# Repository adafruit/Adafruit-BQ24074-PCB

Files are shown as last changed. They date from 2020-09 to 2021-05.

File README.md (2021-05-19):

## Adafruit BQ24074 Solar Charger PCB

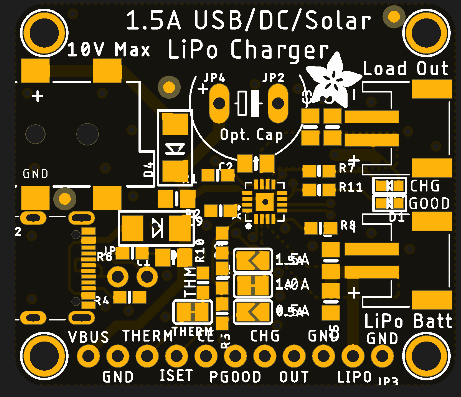
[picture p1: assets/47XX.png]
<a href="https://www.adafruit.com/product/4755"><br/>
Click here to purchase one from the Adafruit shop</a>

PCB files for the Adafruit BQ24074 Solar Charger. 

Format is EagleCAD schematic and board layout
* https://www.adafruit.com/product/4755

### Description

This charger is the only one you need to keep all your Lithium Polymer (LiPoly) or Lithium Ion (LiIon) rechargeable batteries topped up. No matter the power source at your disposal! The Adafruit Universal USB / DC / Solar Lithium Ion/Polymer Charger can use USB, DC or Solar power, with a wide 5-10V input voltage range! The charger chip is super smart, and will reduce the current draw if the input voltage starts to dip under 4.5V, making it a perfect near-MPPT solar charger that you can use with a wide range of panels.

### License

Adafruit invests time and resources providing this open source design, please support Adafruit and open-source hardware by purchasing products from [Adafruit](https://www.adafruit.com)!

Designed by Limor Fried/Ladyada for Adafruit Industries.

Creative Commons Attribution/Share-Alike, all text above must be included in any redistribution. 
See license.txt for additional details.

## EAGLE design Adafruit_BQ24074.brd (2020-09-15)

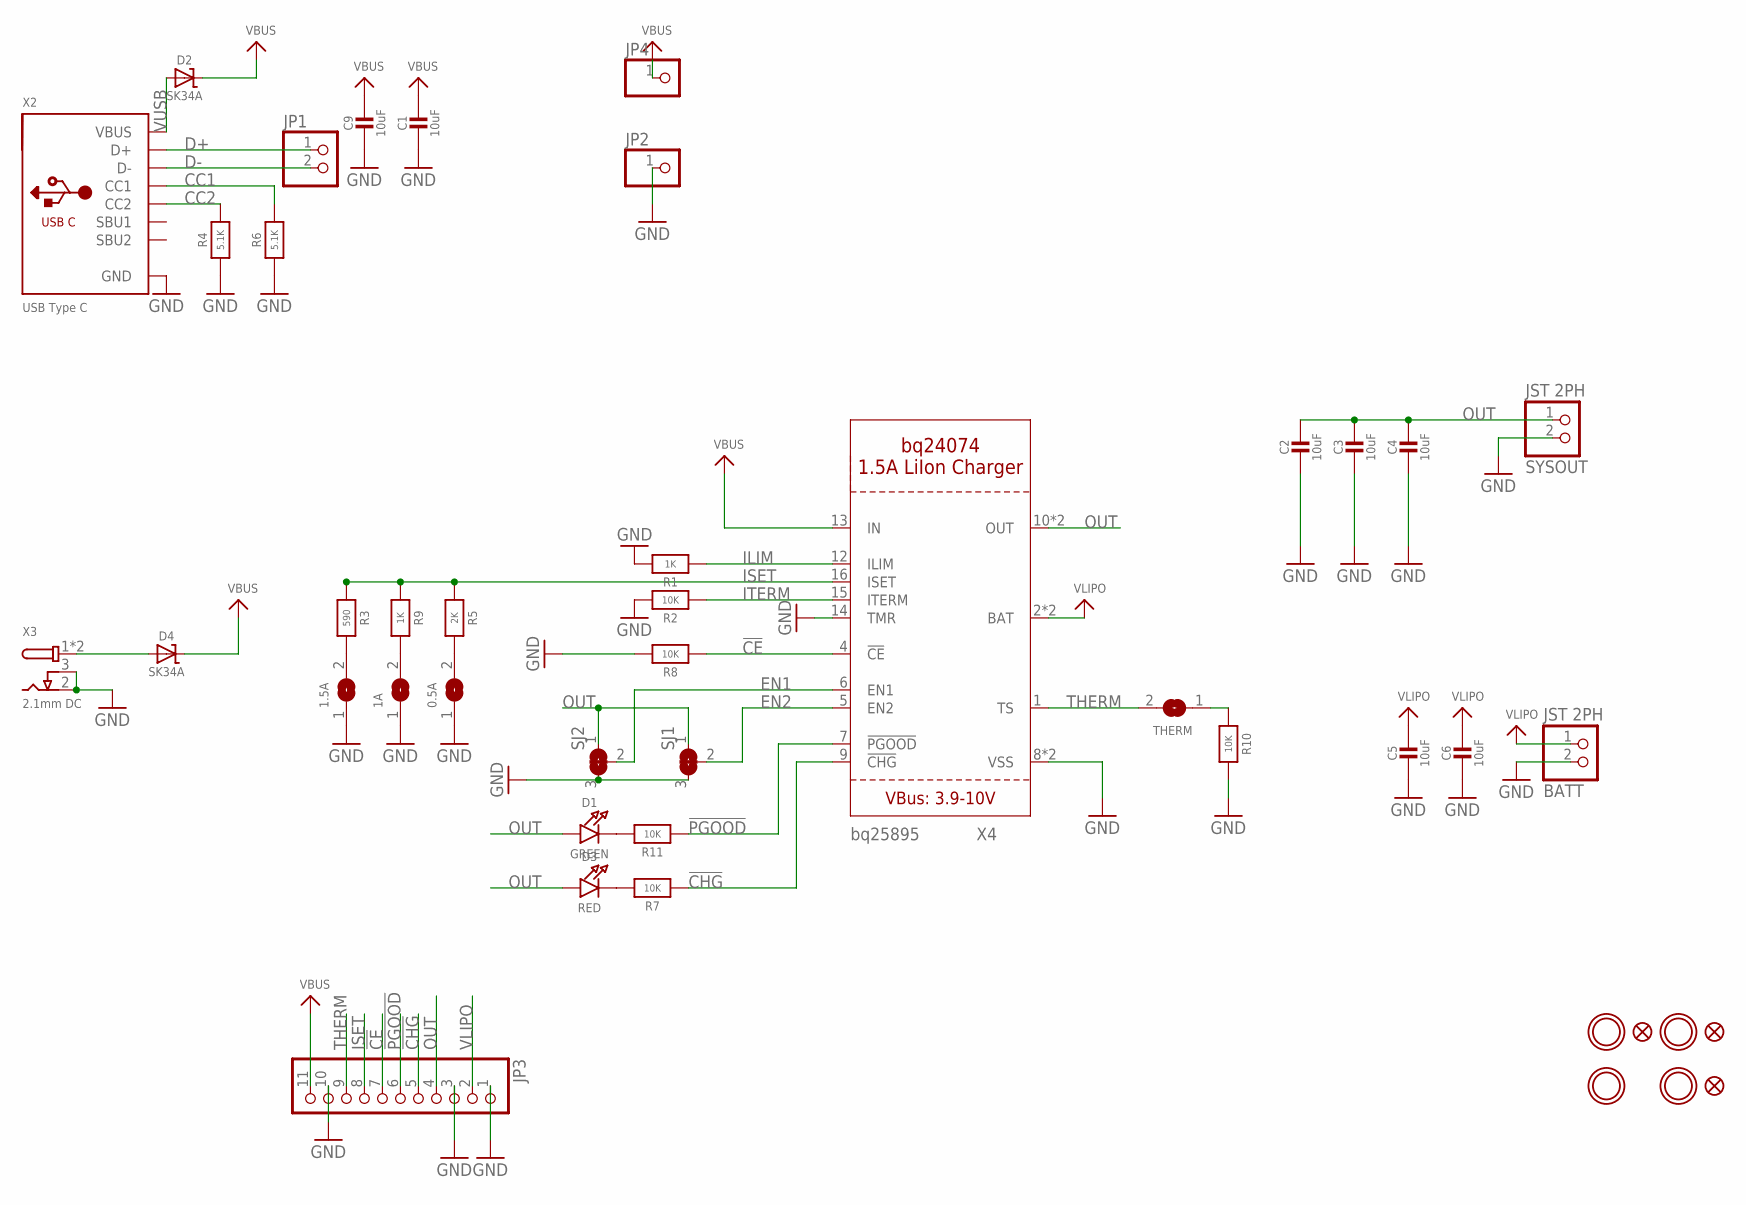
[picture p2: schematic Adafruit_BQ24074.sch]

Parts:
0.5A, 1.5A: SOLDERJUMPER; SOLDERJUMPER_ARROW_NOPASTE
1A: SOLDERJUMPERCLOSED; SOLDERJUMPER_CLOSEDWIRE
BATT: JST 2PH; JST-PH-2-SMT-RA
C1, C2, C3, C4, C5, C6, C9: 10uF; 0805-NO
D1: GREEN; CHIPLED_0603
D2, D4: SK34A; SMADIODE
D3: RED; CHIPLED_0603
FID1, FID2, FID3: FIDUCIAL_1MM
JP1: HEADER-1X2ROUND; 1X02_ROUND
JP2, JP4: HEADER-1X1; 1X01_OVAL
JP3: HEADER-1X1176MIL; 1X11_ROUND_76
R1, R9: 1K; 0603-NO
R2, R7, R8, R10, R11: 10K; 0603-NO
R3: 590; 0603-NO
R4, R6: 5.1K; 0603-NO
R5: 2K; 0603-NO
SJ1, SJ2: SOLDERJUMPER_2WAY; SOLDERJUMPER_2WAY_OPEN_NOPASTE
SYSOUT: JST 2PH; JST-PH-2-SMT-RA
THERM: SOLDERJUMPERCLOSED; SOLDERJUMPER_CLOSEDWIRE
U$3, U$4, U$11, U$12: MOUNTINGHOLE2.5; MOUNTINGHOLE_2.5_PLATED
X2: USB Type C; USB_C_CUSB31-CFM2AX-01-X
X3: 2.1mm DC; DCJACK_2MM_SMT
X4: BQ24074; QFN16_3MM

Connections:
!CE: JP3.7, R8.1, X4.4 (!CE)
!CHG: JP3.5, R7.1, X4.9 (!CHG)
!PGOOD: JP3.6, R11.1, X4.7 (!PGOOD)
CC1: R6.2, X2.A5 (CC1)
CC2: R4.2, X2.B5 (CC2)
D+: JP1.1, X2.A6 (D+), X2.B6 (D+)
D-: JP1.2, X2.A7 (D-), X2.B7 (D-)
EN1: SJ2.2, X4.6 (EN1)
EN2: SJ1.2, X4.5 (EN2)
GND: 0.5A.1, 1.5A.1, 1A.1, BATT.2 (1), C1.2, C2.2, C3.2, C4.2, C5.2, C6.2, C9.2, JP2.1, JP3.1, JP3.3, JP3.10, R1.2, R2.2, R4.1, R6.1, R8.2, R10.2, SJ1.3, SJ2.3, SYSOUT.2 (1), X2.A1B12 (GND), X2.B1A12 (GND), X3.2 (GND), X3.3 (GNDBREAK), X4.8 (VSS), X4.14 (TMR), X4.THERMAL (VSS)
ILIM: R1.1, X4.12 (ILIM)
ISET: JP3.8, R3.1, R5.1, R9.1, X4.16 (ISET)
ITERM: R2.1, X4.15 (ITERM)
unnamed: D1.C, R11.2
unnamed: D4.A, X3.1 (PWR), X3.1' (PWR)
unnamed: D3.C, R7.2
unnamed: 1.5A.2, R3.2
unnamed: 0.5A.2, R5.2
unnamed: 1A.2, R9.2
unnamed: R10.1, THERM.1
OUT: C2.1, C3.1, C4.1, D1.A, D3.A, JP3.4, SJ1.1, SJ2.1, SYSOUT.1 (2), X4.10 (OUT), X4.11 (OUT)
THERM: JP3.9, THERM.2, X4.1 (TS)
VBUS: C1.1, C9.1, D2.C, D4.C, JP3.11, JP4.1, X4.13 (IN)
VLIPO: BATT.1 (2), C5.1, C6.1, JP3.2, X4.2 (BAT), X4.3 (BAT)
VUSB: D2.A, X2.A4B9 (VBUS), X2.B4A9 (VBUS)

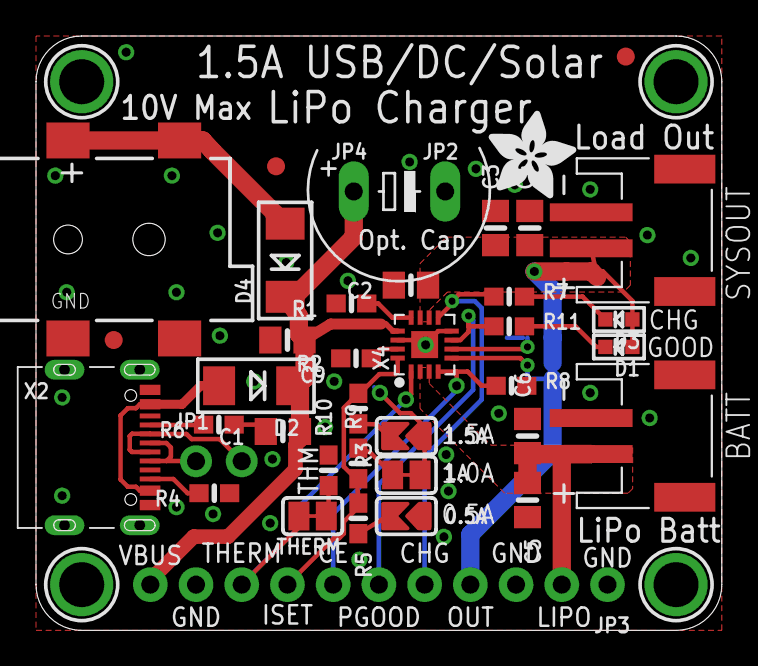
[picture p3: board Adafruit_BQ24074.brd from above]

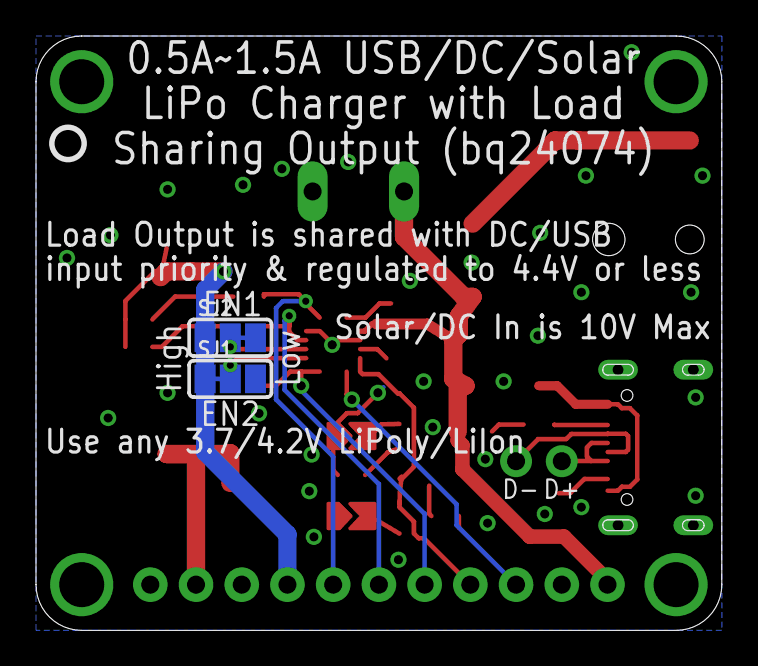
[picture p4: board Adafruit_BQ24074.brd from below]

Board: 2 copper layers, 38.1 x 33.0 mm, 46 parts (3 on the bottom side), 25 nets.

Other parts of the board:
U$14: ADAFRUIT_5MM
U$18: PCBFEAT-REV-040
